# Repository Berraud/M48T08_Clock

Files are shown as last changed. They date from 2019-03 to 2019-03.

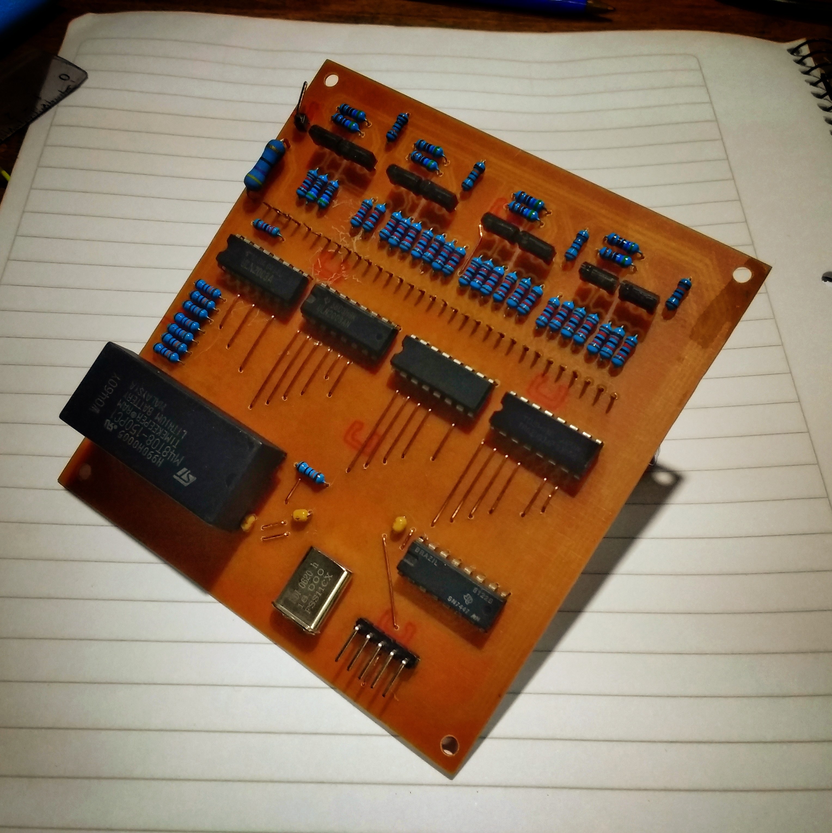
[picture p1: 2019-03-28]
IMG_20190327_114930398-01.jpeg

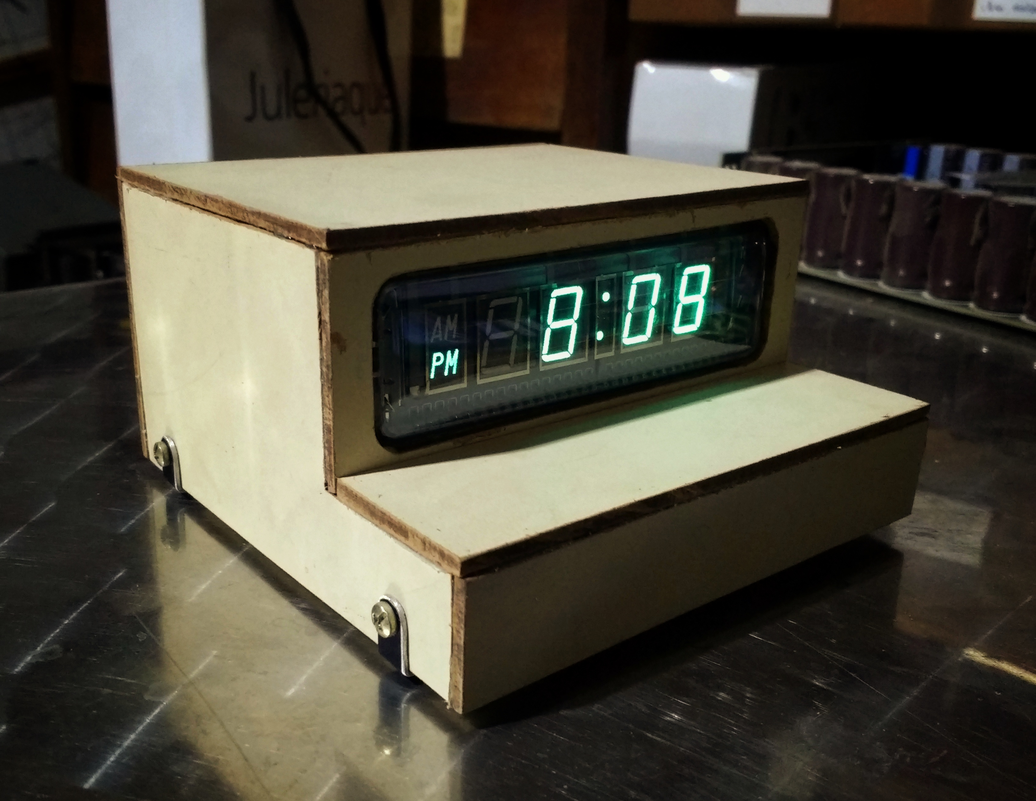
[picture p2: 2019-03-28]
IMG_20190327_200843730-01.jpeg

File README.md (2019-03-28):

# M48T08_Clock
Reloj con RTC M48T08 y ATMEGA328

Reloj diseñado en torno a un display 5-LT-02/02m, un RTC paralelo M48T08 y un ATMEGA328.

Procedimiento para setear la hora:

1) completar los registros con la fecha actual y la hora con algunos minutos a futuro

byte registros[8][8]={{0,0,0,1,1,0,0,1},//año 
                      {0,0,0,0,0,0,1,1},//mes
                      {0,0,1,0,0,0,1,1},//dia 
                      {0,0,0,0,0,1,1,0},//dia semana 
                      {0,0,0,1,0,0,0,1},//horas
                      {0,0,1,1,0,1,0,1},//minutos 
                      {1,0,0,0,0,0,0,0},//segundos
                      {0,0,0,0,0,0,0,0}};//cal
                      
Según hoja de datos el bit más significativo del registro segundos debe ser puesto en 1 primero y en 0 después para asegurar que el RTC comience a correr. Así que se puede cargar eso así sin configurar la hora, y después pasarlo a 0.

2) cargar código
3) Esperar a que sea la hora seteada en los registros y resetear el micro

Nota: No es nada elegante, podría hacerse mediante un menú por serie, o lo que sea, pero funciona y es rápido. Ver pines de conexión en el código. Lo hice con un Mega por disponibilidad de pines, pero podría hacerse también con un Nano

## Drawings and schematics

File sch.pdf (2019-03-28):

ULN2003AN ⁴k7 | 4k7 | 4k7 | 4k7 4k7 | 4k7 | 4k7 | 4k7 2k2 | 2k2 | 2k2 | 2k2 | M⁴⁸T08 | 100n
GND | GND | GND | GND ⁺²⁴V | +²⁴V | +²⁴V | +²⁴V +⁵V +⁵V | +⁵V GND

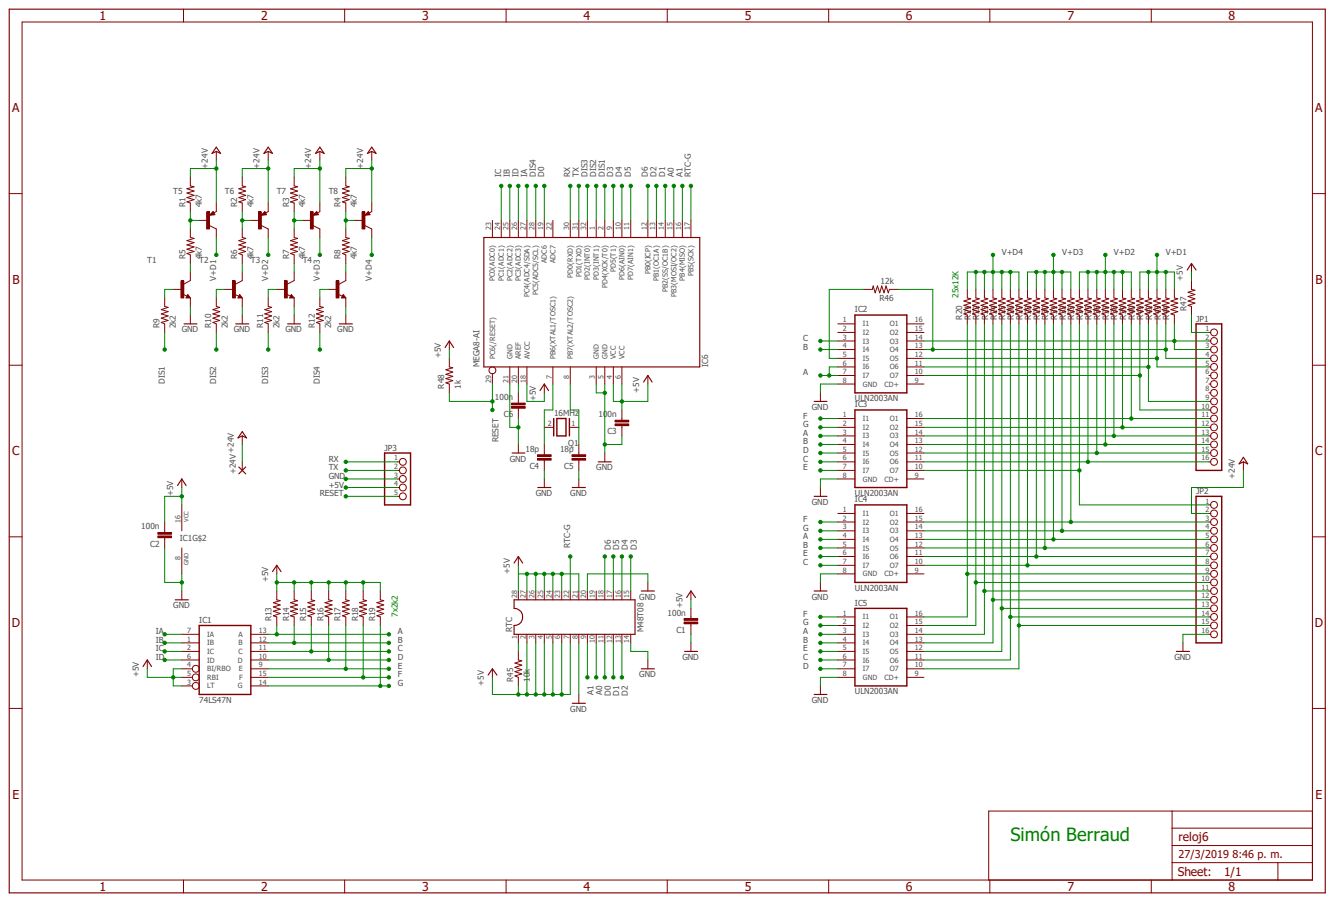
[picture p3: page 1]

6 GND 21 AREF 20 AVCC 18 PB4(MISO) 16 PB3(MOSI/OC2) 15 PB2(SS/OC1B) 14 PB1(OC1A) 13 PB0(ICP) 12 PD7(AIN1) 11 PD6(AIN0) 10 PD5(T1) 9 PD4(XCK/T0) 2 PD3(INT1) 1 PD2(INT0) 32 PD1(TXD) 31 PD0(RXD) 30 ADC7 22 ADC6 19 PC5(ADC5/SCL) 28 PC4(ADC4/SDA) 27 PC3(ADC3) 26 PC2(ADC2) 25 PC1(ADC1) 24 PC0(ADC0) 23 PC6(/RESET) 29

GND⁺⁵V MEGA⁸⁻AI

Simón Berraud

Sheet: 1/1

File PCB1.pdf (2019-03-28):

# R39 R⁴

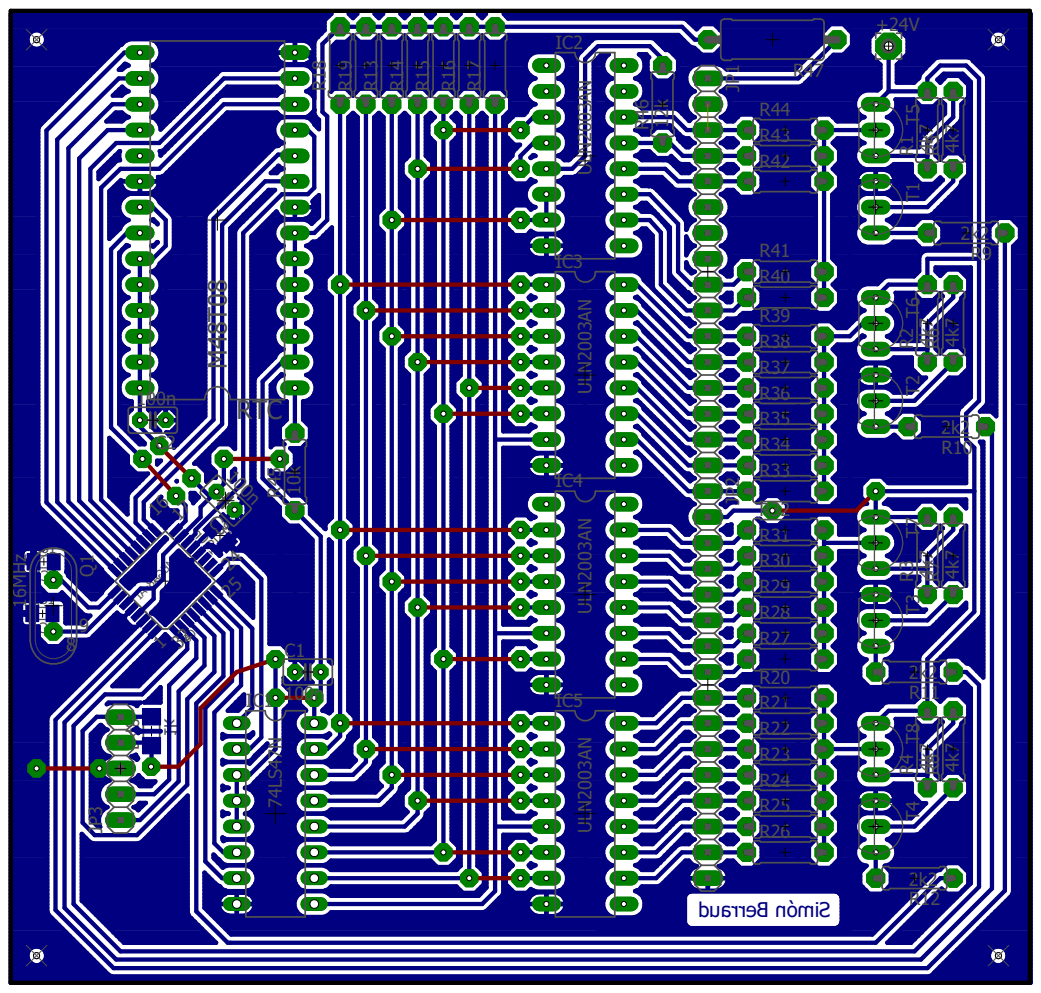
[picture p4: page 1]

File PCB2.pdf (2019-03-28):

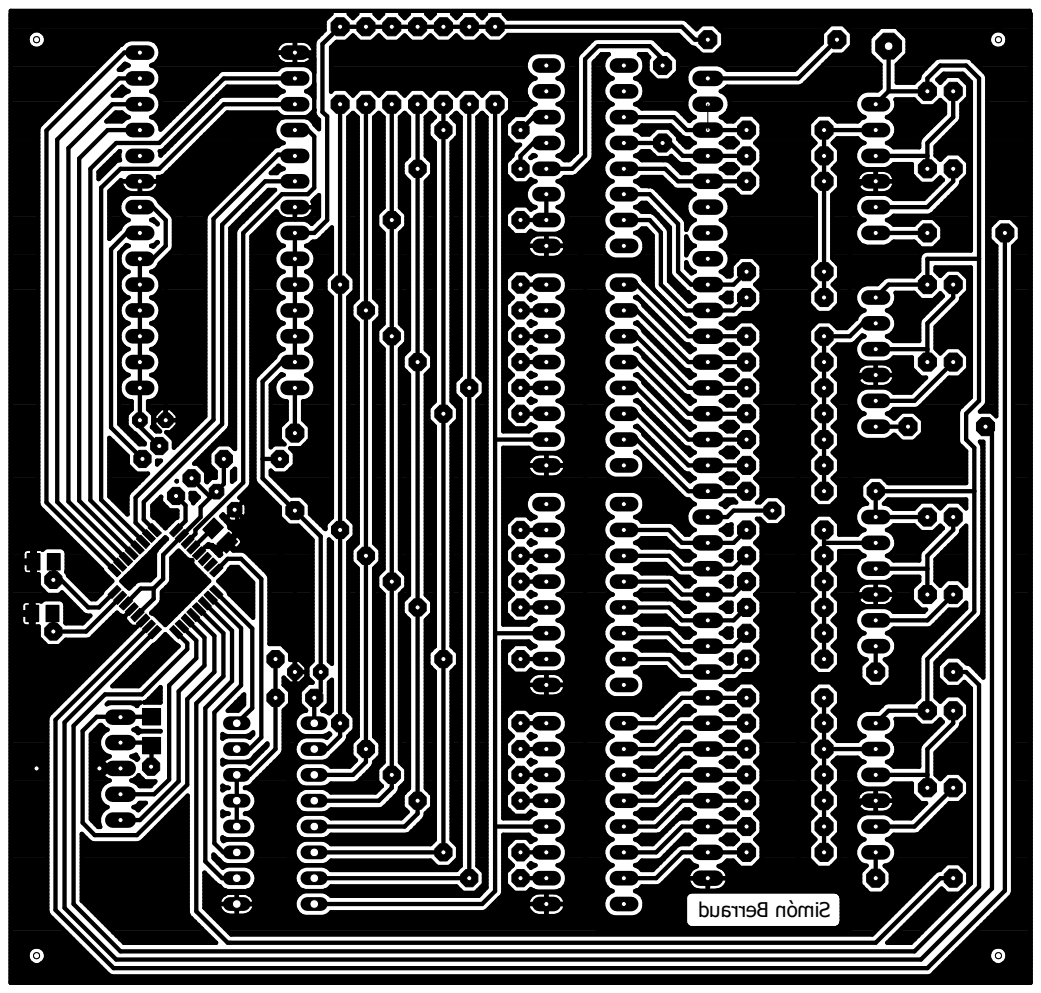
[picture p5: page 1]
Simón Berraud

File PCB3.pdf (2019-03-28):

# R39 R⁴

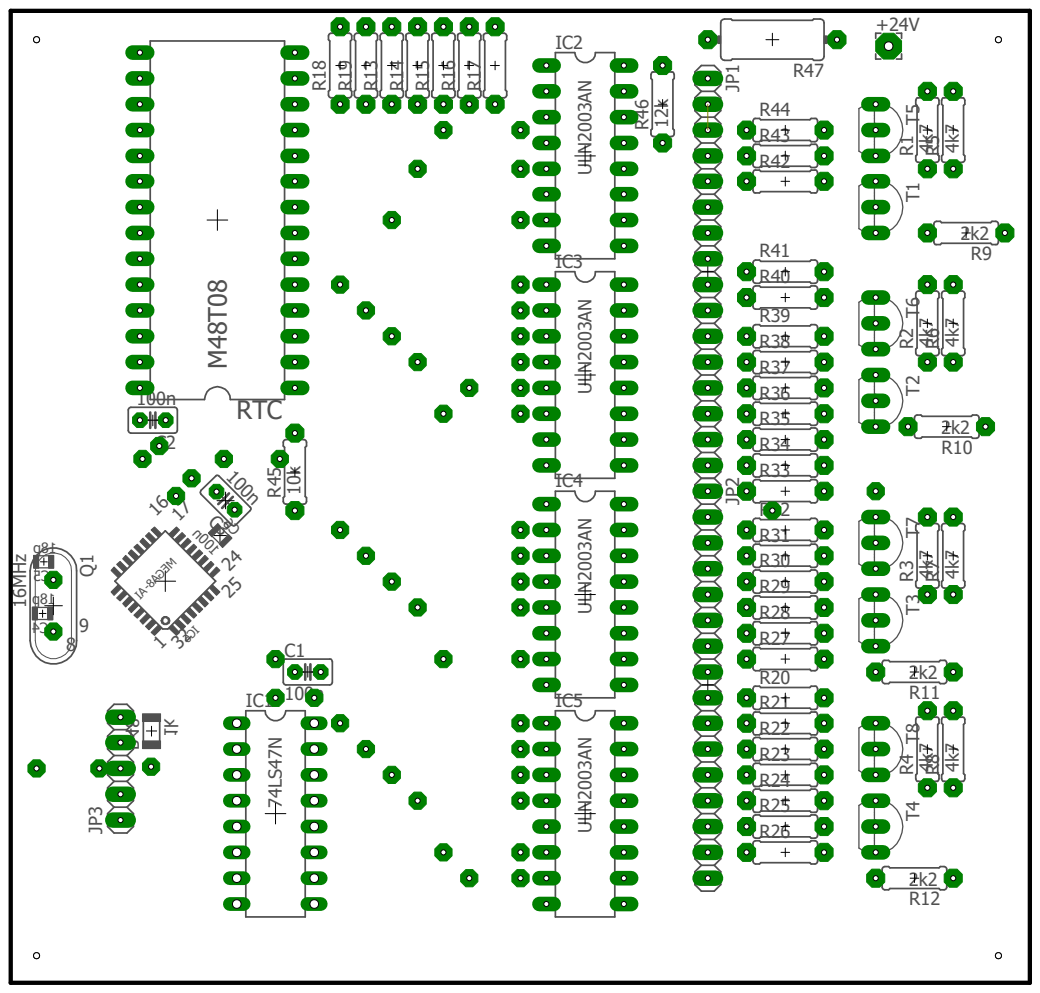
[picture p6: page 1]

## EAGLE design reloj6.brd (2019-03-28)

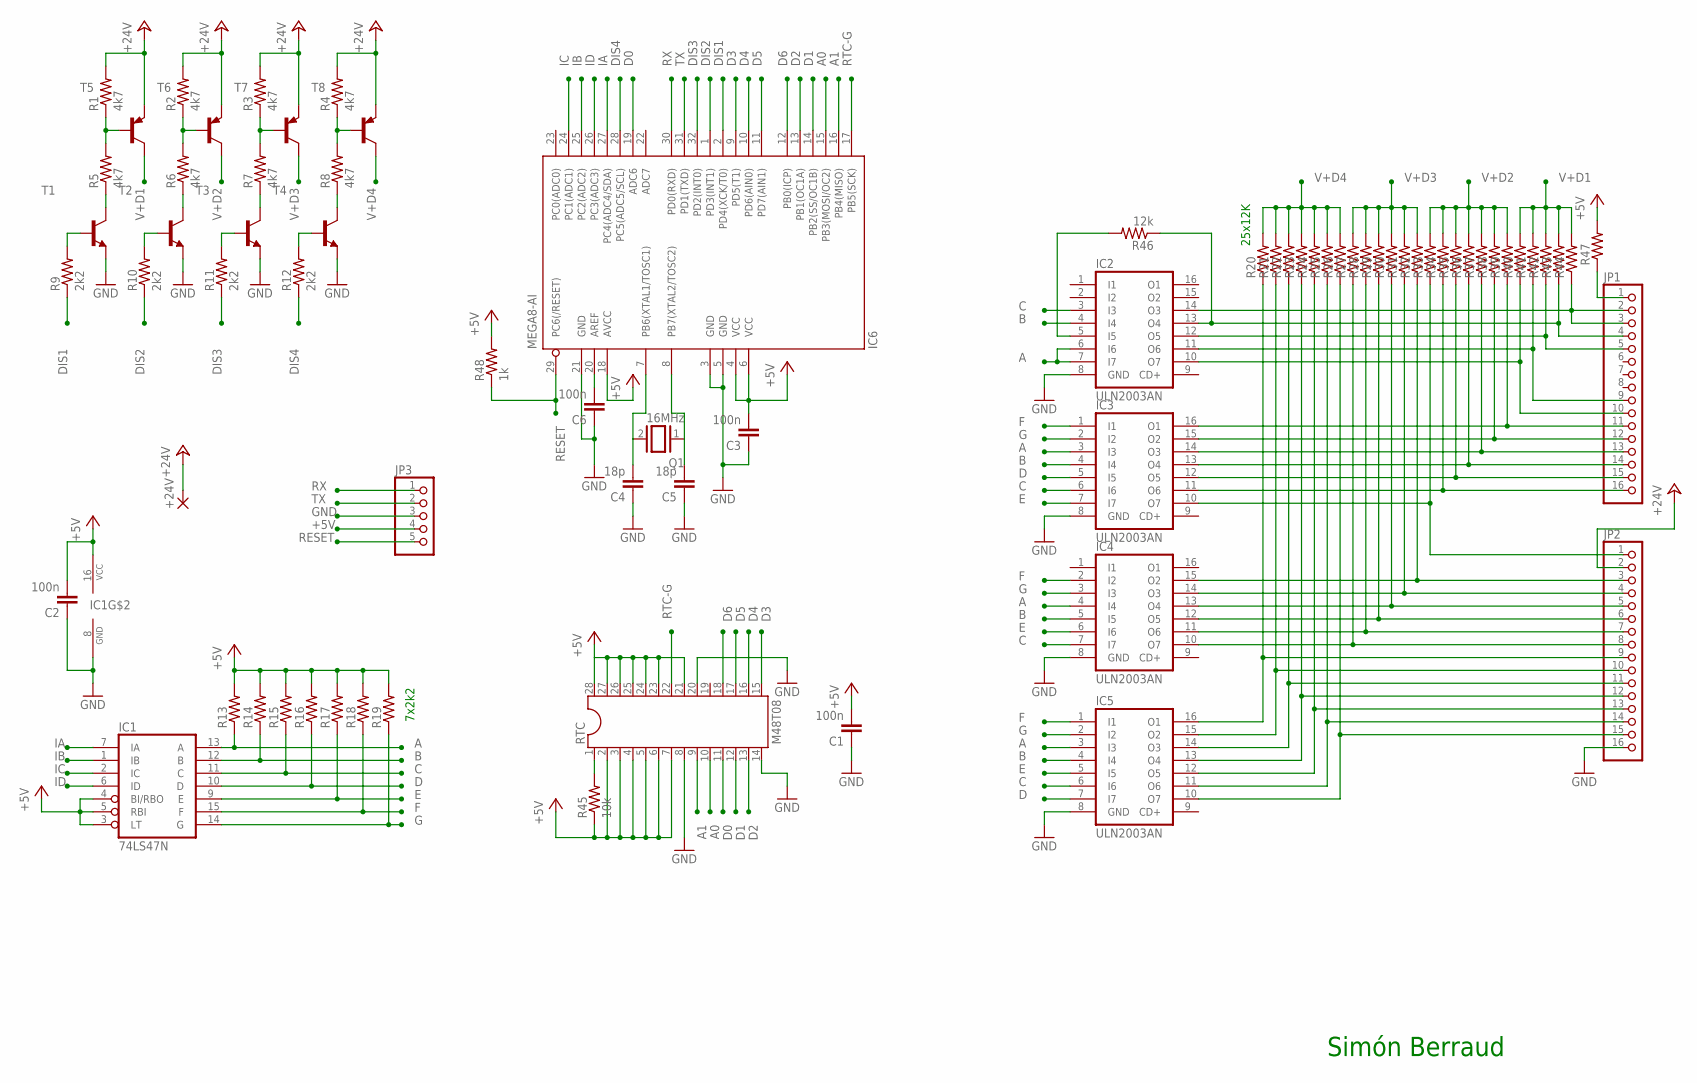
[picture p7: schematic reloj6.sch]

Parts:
+24V: 2,54/0,8
C1, C2, C3: 100n; C025-025X050
C4, C5: 18p; C0805K
C6: 100n; C0805K
IC1: 74LS47N; DIL16
IC2, IC3, IC4, IC5: ULN2003AN; DIL16
IC6: MEGA8-AI; TQFP32-08
JP1, JP2: PINHD-1X16; 1X16
JP3: PINHD-1X5; 1X05
Q1: 16MHz; QS
R1, R2, R3, R4, R5, R6, R7, R8: 4k7; 0207/7
R9, R10, R11, R12: 2k2; 0207/7
R13, R14, R15, R16, R17, R18, R19, R20, R21, R22, R23, R24, R25, R26, R27, R28, R29, R30, R31, R32, R33, R34, R35, R36, R37, R38, R39, R40, R41, R42, R43, R44: R-US_0207/7; 0207/7
R45: 10k; 0207/7
R46: 12k; 0207/7
R47: R-US_0411/12; 0411/12
R48: 1k; R1206
RTC: M48T08; DIL28-6
T1, T2, T3, T4: BC169-NPN-TO92-ECB; TO92-ECB
T5, T6, T7, T8: -PNP-TO92-ECB; TO92-ECB

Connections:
+5V: C1.2, C2.2, C3.2, IC1.3 (LT), IC1.4 (BI/RBO), IC1.5 (RBI), IC1.16 (VCC), IC6.4 (VCC), IC6.6 (VCC), IC6.18 (AVCC), JP3.4, R13.2, R14.2, R15.2, R16.2, R17.2, R18.2, R19.2, R45.1, R47.2, R48.2, RTC.2, RTC.3, RTC.4, RTC.5, RTC.6, RTC.7, RTC.21, RTC.23, RTC.24, RTC.25, RTC.26, RTC.27, RTC.28
+24V: +24V.1, JP2.2, R1.2, R2.2, R3.2, R4.2, T5.E, T6.E, T7.E, T8.E
A: IC1.13 (A), IC2.6 (I6), IC2.7 (I7), IC3.3 (I3), IC4.4 (I4), IC5.3 (I3), R13.1
A0: IC6.15 (PB3(MOSI/OC2)), RTC.10
A1: IC6.16 (PB4(MISO)), RTC.9
B: IC1.12 (B), IC2.4 (I4), IC3.4 (I4), IC4.5 (I5), IC5.4 (I4), R14.1
C: IC1.11 (C), IC2.3 (I3), IC3.6 (I6), IC4.7 (I7), IC5.6 (I6), R15.1
D: IC1.10 (D), IC3.5 (I5), IC5.7 (I7), R16.1
D0: IC6.19 (ADC6), RTC.11
D1: IC6.14 (PB2(SS/OC1B)), RTC.12
D2: IC6.13 (PB1(OC1A)), RTC.13
D3: IC6.9 (PD5(T1)), RTC.15
D4: IC6.10 (PD6(AIN0)), RTC.16
D5: IC6.11 (PD7(AIN1)), RTC.17
D6: IC6.12 (PB0(ICP)), RTC.18
DIS1: IC6.2 (PD4(XCK/T0)), R9.1
DIS2: IC6.1 (PD3(INT1)), R10.1
DIS3: IC6.32 (PD2(INT0)), R11.1
DIS4: IC6.28 (PC5(ADC5/SCL)), R12.1
E: IC1.9 (E), IC3.7 (I7), IC4.6 (I6), IC5.5 (I5), R17.1
F: IC1.15 (F), IC3.1 (I1), IC4.2 (I2), IC5.1 (I1), R18.1
G: IC1.14 (G), IC3.2 (I2), IC4.3 (I3), IC5.2 (I2), R19.1
GND: C1.1, C2.1, C3.1, C4.1, C5.1, C6.1, IC1.8 (GND), IC2.8 (GND), IC3.8 (GND), IC4.8 (GND), IC5.8 (GND), IC6.3 (GND), IC6.5 (GND), IC6.21 (GND), JP2.16, JP3.3, RTC.8, RTC.14, RTC.20, T1.E, T2.E, T3.E, T4.E
IA: IC1.7 (IA), IC6.27 (PC4(ADC4/SDA))
IB: IC1.1 (IB), IC6.25 (PC2(ADC2))
IC: IC1.2 (IC), IC6.24 (PC1(ADC1))
ID: IC1.6 (ID), IC6.26 (PC3(ADC3))
unnamed: R9.2, T1.B
unnamed: R10.2, T2.B
unnamed: R11.2, T3.B
unnamed: R12.2, T4.B
unnamed: JP1.1, R47.1
unnamed: R1.1, R5.2, T5.B
unnamed: R2.1, R6.2, T6.B
unnamed: R3.1, R7.2, T7.B
unnamed: R4.1, R8.2, T8.B
unnamed: R5.1, T1.C
unnamed: R6.1, T2.C
unnamed: R45.2, RTC.1
unnamed: R7.1, T3.C
unnamed: R8.1, T4.C
unnamed: C4.2, IC6.7 (PB6(XTAL1/TOSC1)), Q1.2
unnamed: IC5.16 (O1), JP2.9, R20.1
unnamed: C5.2, IC6.8 (PB7(XTAL2/TOSC2)), Q1.1
unnamed: C6.2, IC6.20 (AREF)
unnamed: IC3.13 (O4), JP1.14, R36.1
unnamed: IC3.11 (O6), JP1.16, R34.1
unnamed: IC4.14 (O3), JP2.4, R31.1
unnamed: IC4.12 (O5), JP2.6, R29.1
unnamed: IC4.11 (O6), JP2.7, R28.1
unnamed: IC2.13 (O4), JP1.4, R43.1, R46.1
unnamed: IC2.5 (I5), R46.2
unnamed: IC2.10 (O7), JP1.10, R40.1
unnamed: IC2.11 (O6), JP1.9, R41.1
unnamed: IC2.12 (O5), JP1.5, R42.1
unnamed: IC2.14 (O3), JP1.2, JP1.3, R44.1
unnamed: IC3.16 (O1), JP1.11, R39.1
unnamed: IC3.15 (O2), JP1.12, R38.1
unnamed: IC3.14 (O3), JP1.13, R37.1
unnamed: IC3.12 (O5), JP1.15, R35.1
unnamed: IC3.10 (O7), JP2.1, R33.1
unnamed: IC4.15 (O2), JP2.3, R32.1
unnamed: IC4.13 (O4), JP2.5, R30.1
unnamed: IC4.10 (O7), JP2.8, R27.1
unnamed: IC5.15 (O2), JP2.10, R21.1
unnamed: IC5.14 (O3), JP2.11, R22.1
unnamed: IC5.13 (O4), JP2.12, R23.1
unnamed: IC5.12 (O5), JP2.13, R24.1
unnamed: IC5.11 (O6), JP2.14, R25.1
unnamed: IC5.10 (O7), JP2.15, R26.1
RESET: IC6.29 (PC6(/RESET)), JP3.5, R48.1
RTC-G: IC6.17 (PB5(SCK)), RTC.22
RX: IC6.30 (PD0(RXD)), JP3.1
TX: IC6.31 (PD1(TXD)), JP3.2
V+D1: R40.2, R41.2, R42.2, R43.2, R44.2, T5.C
V+D2: R33.2, R34.2, R35.2, R36.2, R37.2, R38.2, R39.2, T6.C
V+D3: R27.2, R28.2, R29.2, R30.2, R31.2, R32.2, T7.C
V+D4: R20.2, R21.2, R22.2, R23.2, R24.2, R25.2, R26.2, T8.C

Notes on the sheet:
25x12K
7x2k2
Simón Berraud

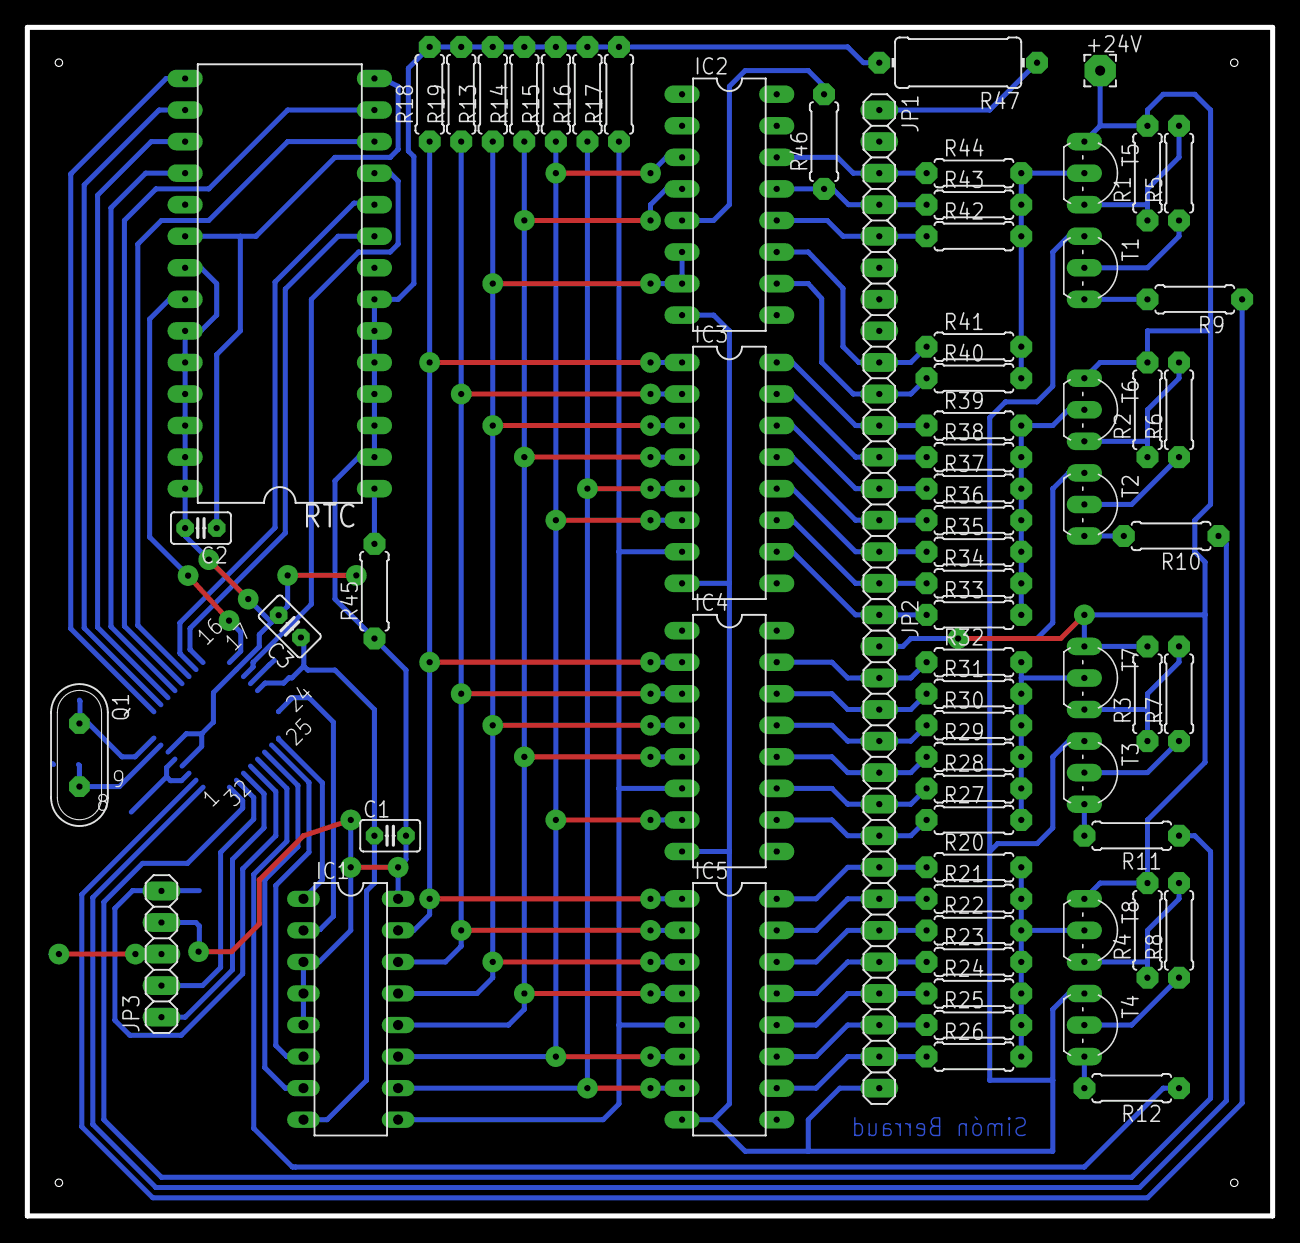
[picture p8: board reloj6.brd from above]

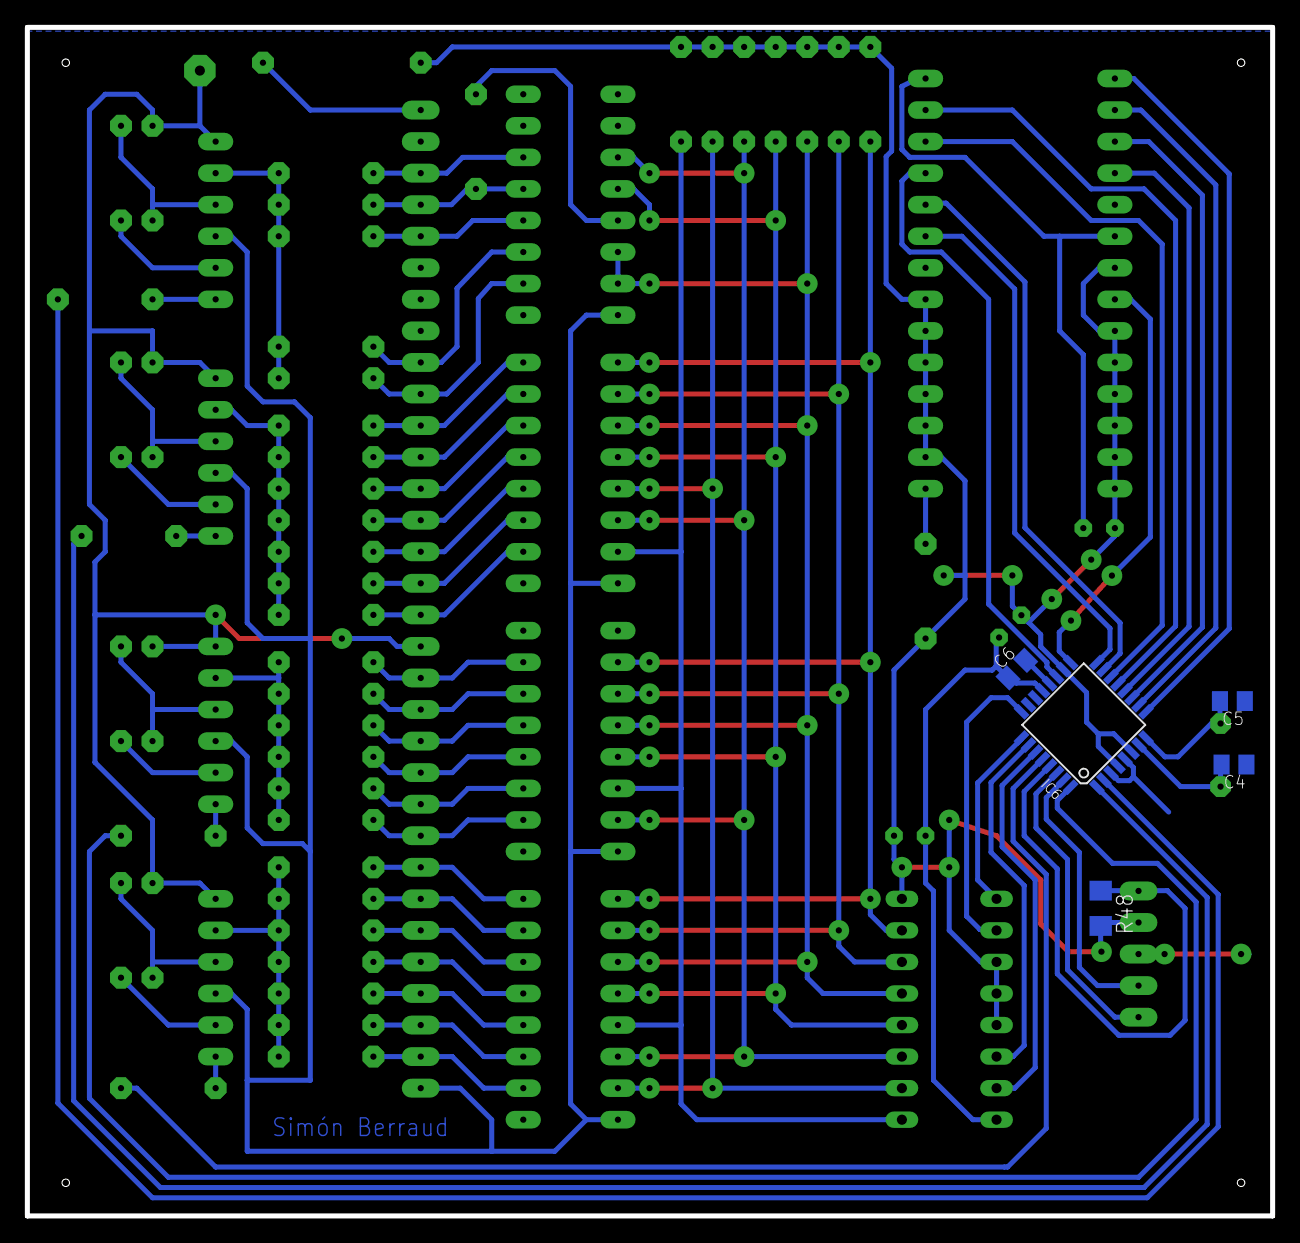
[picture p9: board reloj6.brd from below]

Board: 2 copper layers, 100.2 x 95.7 mm, 74 parts (5 on the bottom side), 78 nets.

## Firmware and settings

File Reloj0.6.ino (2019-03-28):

#include <FrequencyTimer2.h>


int timerRTC=100;
int d0=0;
int d1=0;
int d2=0;
int d3=0;
byte setadd=0;
byte datolisto=0;
int reg=0;

byte registros[3][8]={{0,0,0,0,0,0,0,0},//horas
                      {0,0,0,0,0,0,0,0},//minutos
                      {0,0,0,0,0,0,0,0}};//segundos

byte horasC[24][8]={{0,0,0,0,0,0,0,0},//00 lo necesito para setear PM
                    {0,0,0,0,0,0,0,1},//01
                    {0,0,0,0,0,0,1,0},//02
                    {0,0,0,0,0,0,1,1},//03
                    {0,0,0,0,0,1,0,0},//04
                    {0,0,0,0,0,1,0,1},//05
                    {0,0,0,0,0,1,1,0},//06
                    {0,0,0,0,0,1,1,1},//07
                    {0,0,0,0,1,0,0,0},//08
                    {0,0,0,0,1,0,0,1},//09
                    {0,0,0,1,0,0,0,0},//10
                    {0,0,0,1,0,0,0,1},//11
                    {0,0,0,1,0,0,1,0},//12 lo necesito para setear PM
                    {0,0,0,1,0,0,1,1},//13
                    {0,0,0,1,0,1,0,0},//14
                    {0,0,0,1,0,1,0,1},//15
                    {0,0,0,1,0,1,1,0},//16
                    {0,0,0,1,0,1,1,1},//17
                    {0,0,0,1,1,0,0,0},//18
                    {0,0,0,1,1,0,0,1},//19
                    {0,0,1,0,0,0,0,0},//20
                    {0,0,1,0,0,0,0,1},//21
                    {0,0,1,0,0,0,1,0},//22
                    {0,0,1,0,0,0,1,1}};//23


byte PM=0;
byte minutoCero=0;
byte puntitos=0;

byte regHoras[12]={0,0,0,0,0,0,0,0,0,0,0,0}; //a la hora de comparar las horas evalúo si la hora actual es disinta a los registros para corregirla
byte simbolo[4]={0,0,0,0};

int dir[3] = {12, 11}; //A1 A0
int datos[7] ={8,7,6,5,9,10,20}; //D6 D0

#define G 13

byte col = 0;
byte leds[4][4]; //en esta actualizar el dato a mostrar en display

// pin[xx] on led matrix connected to nn on Arduino (-1 is dummy to make array start at pos 1)
int pins[9]= {-1, 4, 3, 2, 19, 17, 15, 16, 18};//dummy dis1 - dis4/ ID-IA

// col[xx] of leds = pin yy on led matrix
int cols[4] = {pins[1], pins[2], pins[3], pins[4]};//dis1,dis2,dis3,dis4

// row[xx] of leds = pin yy on led matrix
int rows[4] = {pins[5], pins[6], pins[7], pins[8]};//ID,IC,IB,IA

int pattern[4] = {0,0,0,0};

void setup() {
  // sets the pins as output
  for (int i = 1; i <= 8; i++) {
    pinMode(pins[i], OUTPUT);
  }

  for (int i = 0; i < 2; i++) {//este
    pinMode(dir[i], OUTPUT);
  }

  for (int i = 0; i < 7; i++) {//y este
    pinMode(datos[i], INPUT);
  }

  // set up cols and rows
  for (int i = 1; i <= 4; i++) {
    digitalWrite(cols[i - 1], LOW);
  }

  for (int i = 1; i <= 4; i++) {
    digitalWrite(rows[i - 1], LOW);
  }

  clearLeds();

  // Turn off toggling of pin 11
  FrequencyTimer2::disable();
  // Set refresh rate (interrupt timeout period)
  FrequencyTimer2::setPeriod(2000);
  // Set interrupt routine to be called
  FrequencyTimer2::setOnOverflow(display);

 
  Serial.begin(9600);

  //------------Lectura inicial para cuando reinicia. Después sólo leo si min=00
  LeerMinutos();
  LeerHoras();
  CoregirHora();
  CargarMatrizLed();
}

void loop() {
    
    if(!timerRTC)
    {
      LeerMinutos();
      if(minutoCero)
        {
        LeerHoras();
        CoregirHora();  
        }
      LeerSegundos();
      if(registros[2][7]==1)
        puntitos=1;
      else
        puntitos=0;

      //tres variables que determinan el código: PM, puntito y registros[0][3]
      
      CorreccionSimbolos(); //a 1 / b=AM/PM c=puntitos
      
        
      CargarMatrizLed();

      timerRTC=100;
    }
    
}

void LeerMinutos()
{   
  digitalWrite(G,1);
  
  //dirección
  digitalWrite(dir[0],1);//A1 
  digitalWrite(dir[1],0);//A0 
  
 
  digitalWrite(G,0);
  minutoCero=1;
  for(int i=0;i<6;i++)
      {
      registros[1][i+1]=digitalRead(datos[i]);
      if(registros[1][i+1]==1) minutoCero=0;//si encuentro un 1 en el registro de minutos quiere decir que no es cero, y minutoCero pasa a 0, sino queda en 1;
      }
      if(analogRead(datos[6])>512)
        {
        registros[1][7]=1;
        minutoCero=0; //acá también xq el último bit lo leo analógicamente
        }
      else
        registros[1][7]=0;
}

void LeerHoras()
{
   digitalWrite(G,1);
  
  //dirección
  digitalWrite(dir[0],1);//A1 1FFBh Horas
  digitalWrite(dir[1],1);//A0 
  
  
  digitalWrite(G,0);
  
  for(int i=0;i<6;i++)
      registros[0][i+1]=digitalRead(datos[i]);

      if(analogRead(datos[6])>512)
        registros[0][7]=1;
      else
        registros[0][7]=0;
}

void LeerSegundos()
{
  digitalWrite(G,1);
  
  digitalWrite(dir[0],0);//A1 10 1FF9h segundos
  digitalWrite(dir[1],1);//A0 11
  
  
  digitalWrite(G,0);
   //sólo me interesa el bit menos significativo para titilar los puntitos
  
  if(analogRead(datos[6])>512)
    registros[2][7]=1;
  else
    registros[2][7]=0;
}

void CoregirHora()
{
  //verificar si son más de las 12
  for(int j=0; j<12; j++)
    {
    regHoras[j]=1; //lo pongo en 1. Si la comparación da que son distintos lo paso a cero. El que queda en 1 es el correcto
    
    for(int i=0; i<8; i++)
      {
        if(registros[0][i]!=horasC[j+12][i]) 
        {
          regHoras[j]=0; //registros[0] hora vs 12/23
        }
      }
    }
  //setear PM
  
  PM=0;
  
  for(int i=0;i<12;i++)
    if(regHoras[i]==1) PM=1;
    
  //corregir a la hora en formato 12hs
  for(int i=1;i<12;i++) //si es 12 no lo corrijo
    if(regHoras[i]) //si encontré una a corregir regHoras[1]=13 
      for(int j=0;j<8;j++) //actualizo todos los bits del registro hora
        registros[0][j]=horasC[i][j];
}

void CorreccionSimbolos()
{
  //cargar símbolos en primer digito
  if(!registros[0][3] && !PM && !puntitos) //1010
    {
    simbolo[0]=1;
    simbolo[1]=0;
    simbolo[2]=1;
    simbolo[3]=0;
    }
   if(!registros[0][3] && !PM && puntitos) //1011
    {
    simbolo[0]=1;
    simbolo[1]=0;
    simbolo[2]=1;
    simbolo[3]=1;
    }
     if(!registros[0][3] && PM && !puntitos) //1100
    {
    simbolo[0]=1;
    simbolo[1]=1;
    simbolo[2]=0;
    simbolo[3]=0;
    }
     if(!registros[0][3] && PM && puntitos) //0100
    {
    simbolo[0]=0;
    simbolo[1]=1;
    simbolo[2]=0;
    simbolo[3]=0;
    }
     if(registros[0][3] && !PM && !puntitos) //1101
    {
    simbolo[0]=1;
    simbolo[1]=1;
    simbolo[2]=0;
    simbolo[3]=1;
    }
     if(registros[0][3] && !PM && puntitos) //0101
    {
    simbolo[0]=0;
    simbolo[1]=1;
    simbolo[2]=0;
    simbolo[3]=1;
    }
     if(registros[0][3] && PM && !puntitos) //0010
    {
    simbolo[0]=0;
    simbolo[1]=0;
    simbolo[2]=1;
    simbolo[3]=0;
    }
     if(registros[0][3] && PM && puntitos) //0000
    {
    simbolo[0]=0;
    simbolo[1]=0;
    simbolo[2]=0;
    simbolo[3]=0;
    }
}

void CargarMatrizLed()
{
  for (int j = 0; j < 4; j++) {
      leds[j][0] = simbolo[j];
      leds[j][1] = registros[0][4+j];
      leds[j][2] = registros[1][j];
      leds[j][3] = registros[1][4+j];
      }
}

void clearLeds() {
  // Clear display array
  for (int i = 0; i < 4; i++) {
    for (int j = 0; j < 4; j++) {
      leds[i][j] = 0; //leds es la variable en donde están almacenados los datos a sacar al momento de la interrupción
    }
  }
}


// Interrupt routine
void display() {
  digitalWrite(cols[col], LOW);  // Turn whole previous column off
  col++;
  if (col == 4) 
    {
    col = 0;
    }
  for (int row = 0; row < 4; row++) 
    {
    if (leds[row][col] == 1) 
      {
      digitalWrite(rows[row], HIGH);  // Turn on this led
      //Serial.print("0");
      }
    else 
    {
      digitalWrite(rows[row], LOW); // Turn off this led
      //Serial.print("1");
      }
    }
  digitalWrite(cols[col], HIGH); // Turn whole column on at once (for equal lighting times)
  
  //------contadores
  
  if(timerRTC) timerRTC--;
}

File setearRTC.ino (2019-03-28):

#include <FrequencyTimer2.h>

int timerRTC=100;

byte registros[8][8]={{0,0,0,1,1,0,0,1},//año 19  D7....D0
                      {0,0,0,0,0,0,1,1},//mes 2
                      {0,0,1,0,0,0,1,1},//dia 27
                      {0,0,0,0,0,1,1,0},//dia semana 4
                      {0,0,0,1,0,0,0,1},//horas 23
                      {0,0,1,1,0,1,0,1},//minutos 
                      {1,0,0,0,0,0,0,0},//segundos
                      {0,0,0,0,0,0,0,0}};//cal

int dir[3] = {10, 11, 12}; //A2 A1 A0

int datos[8] ={30,31,32,33,34,35,36,37}; //D7 D6... D0
//int datos[8] ={37,36,35,34,33,32,31,30}; //D7 D6... D0

#define G 2
#define W 3

void setup() {
//------------------------------------------PINES
for (int i = 0; i < 3; i++) {
    pinMode(dir[0], OUTPUT);
    pinMode(dir[1], OUTPUT);
    pinMode(dir[2], OUTPUT);
  }

  for (int i = 0; i < 8; i++) {
    pinMode(datos[i], OUTPUT);
    }

  pinMode(G,OUTPUT); //pin 2
  pinMode(W,OUTPUT); //pin 3

//--------------------------------------------------------------INICIO CONFIGURACIÓN
  //poner en modo de escritura
  digitalWrite(G,1);
  digitalWrite(W,1);
  //dirección
  digitalWrite(dir[0],0);//A2 10 1FF8h control
  digitalWrite(dir[1],0);//A1 11
  digitalWrite(dir[2],0);//A0 12
  //delay(1);
  digitalWrite(W,0); //habilito escritura
  
  //poner en 1 bit W de registro de control
  registros[7][0]=1; //si esto no está en uno no debería actualizar los registros del RTC. Puedo probar apagar entre medio
  for(int i=0;i<8;i++)
      digitalWrite(datos[i],registros[7][i]); //paso a los pines de datos el valor del registro de control
      
  delay(1);//espero un toque a que tDVWH (150ns?)
  digitalWrite(W,1); //deshabilito escritura
  delay(1);//espero un toque a que tWHDH (150ns?)
  //actualizar todos los registros menos estado
  //dirección
  digitalWrite(dir[0],1);//10 1FFFh año
  digitalWrite(dir[1],1);//11
  digitalWrite(dir[2],1);//12

  digitalWrite(W,0); //habilito escritura
  
  for(int i=0;i<8;i++)
      digitalWrite(datos[i],registros[0][i]); //año

  delay(1);//espero un toque a que tDVWH (150ns?)

    digitalWrite(W,1); //deshabilito escritura
  delay(1);//espero un toque a que tWHDH (150ns?)
  //actualizar todos los registros menos estado
  //dirección
  digitalWrite(dir[0],1);//10 1FFEh mes
  digitalWrite(dir[1],1);//11
  digitalWrite(dir[2],0);//12

  digitalWrite(W,0); //habilito escritura
  
  for(int i=0;i<8;i++)
      digitalWrite(datos[i],registros[1][i]); //año

  delay(1);//espero un toque a que tDVWH (150ns?)

    digitalWrite(W,1); //deshabilito escritura
  delay(1);//espero un toque a que tWHDH (150ns?)
  //actualizar todos los registros menos estado
  //dirección
  digitalWrite(dir[0],1);//10 1FFDh dia
  digitalWrite(dir[1],0);//11
  digitalWrite(dir[2],1);//12

  digitalWrite(W,0); //habilito escritura
  
  for(int i=0;i<8;i++)
      digitalWrite(datos[i],registros[2][i]); //año --------------------

  delay(1);//espero un toque a que tDVWH (150ns?)

    digitalWrite(W,1); //deshabilito escritura
  delay(1);//espero un toque a que tWHDH (150ns?)
  //actualizar todos los registros menos estado
  //dirección
  digitalWrite(dir[0],1);//10 1FFCh dia semana
  digitalWrite(dir[1],0);//11
  digitalWrite(dir[2],0);//12

  digitalWrite(W,0); //habilito escritura
  
  for(int i=0;i<8;i++)
      digitalWrite(datos[i],registros[3][i]); //año

  delay(1);//espero un toque a que tDVWH (150ns?)

    digitalWrite(W,1); //deshabilito escritura
  delay(1);//espero un toque a que tWHDH (150ns?)
  //actualizar todos los registros menos estado
  //dirección
  digitalWrite(dir[0],0);//10 1FFBh horas
  digitalWrite(dir[1],1);//11
  digitalWrite(dir[2],1);//12

  digitalWrite(W,0); //habilito escritura
  
  for(int i=0;i<8;i++)
      digitalWrite(datos[i],registros[4][i]); //horas

  delay(1);//espero un toque a que tDVWH (150ns?)

    digitalWrite(W,1); //deshabilito escritura
  delay(1);//espero un toque a que tWHDH (150ns?)
  //actualizar todos los registros menos estado
  //dirección
  digitalWrite(dir[0],0);//10 1FFAh minutos
  digitalWrite(dir[1],1);//11
  digitalWrite(dir[2],0);//12

  digitalWrite(W,0); //habilito escritura
  
  for(int i=0;i<8;i++)
      digitalWrite(datos[i],registros[5][i]); //minutos

  delay(1);//espero un toque a que tDVWH (150ns?)
  //pasar de nuvo a cero el bit W

    digitalWrite(W,1); //deshabilito escritura
  delay(1);//espero un toque a que tWHDH (150ns?)
  //actualizar todos los registros menos estado
  //dirección
  digitalWrite(dir[0],0);//A2 //10 1FF9h segundos
  digitalWrite(dir[1],0);//A1 //11
  digitalWrite(dir[2],1);//A0 //12

  digitalWrite(W,0); //habilito escritura
  
  for(int i=0;i<8;i++)
      digitalWrite(datos[i],registros[6][i]); //segundos

  delay(1);//espero un toque a que tDVWH (150ns?)

  //poner en 0 bit W de registro de control
  registros[7][0]=0;

 digitalWrite(W,1);
  //dirección
  digitalWrite(dir[0],0);//10 1FF8h control
  digitalWrite(dir[1],0);//11
  digitalWrite(dir[2],0);//12
  //delay(1);
  digitalWrite(W,0); //habilito escritura
  
  //poner en 1 bit W de registro de control
  
  for(int i=0;i<8;i++)
      digitalWrite(datos[i],registros[7][i]); //paso a los pines de datos el valor del registro de control
      
  delay(1);//espero un toque a que tDVWH (150ns?)
  digitalWrite(W,1); //deshabilito escritura

  
}

void loop() {
  // put your main code here, to run repeatedly:
  //poner en modo de escritura
  //poner en 1 bit W de registro de control
  //actualizar todos los registros menos estado
  //pasar de nuvo a cero el bit W
  
}
